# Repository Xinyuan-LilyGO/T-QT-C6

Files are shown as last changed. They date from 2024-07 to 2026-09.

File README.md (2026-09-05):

<h1 align="center">T-QT-C6</h1>

## **English** | [中文](./README_CN.md)





<p align="center">
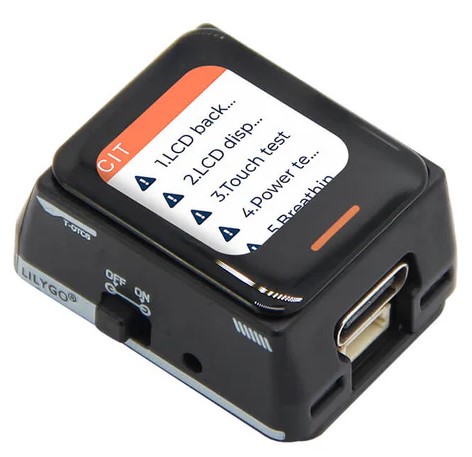
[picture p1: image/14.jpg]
T-QT-C6
  
</p>

## Overview

T-QT-C6 is a compact development board based on the ESP32-C6, with a 0.85-inch 128 × 128 LCD, capacitive touch, battery measurement, charging management, and an RGB breathing LED. An optional battery backboard adds a battery connector and an LSM6DSL inertial sensor.

[Purchase from the LILYGO store](https://lilygo.cc/products/t-qt-c6)

## Directory

- [Device Versions](#device-versions)
- [Notes](#notes)
- [Preview](#preview)
- [Supported Development Environments](#supported-development-environments)
- [Quick Start](#quick-start)
- [Examples](#examples)
- [Prebuilt Firmware](#prebuilt-firmware)
- [Hardware Modules](#hardware-modules)
- [Pin Overview](#pin-overview)
- [Power Consumption](#power-consumption)
- [Project Materials](#project-materials)
- [FAQ](#faq)

## Device Versions

| Version | Release date | Main change |
| :-- | :-- | :-- |
| T-QT-C6 V1.0 | 2023-12-20 | Initial release |
| T-QT-C6 V1.1 | 2024-03-27 | Added battery backboard support |
| T-QT-C6 V1.2 | 2024-06-13 | Replaced the charging IC with SGM41562 |
| T-QT-C6 Battery V1.2 | 2025-08-11 | Changed the battery connector to a 2-pin, 1.25 mm connector |

## Notes

- Select the connected battery backboard version in [`libraries/common/pin_config.h`](./libraries/common/pin_config.h). The default configuration is `T_QT_C6_Battery_V1_2`.
- Battery V1.2 uses a two-wire battery connection (VBAT and GND) without an external NTC thermistor. The SGM41562 application example therefore disables external NTC detection.
- `Arduino_GFX` and `cpp_bus_driver` are Git submodules. Clone this repository recursively or initialize the submodules before building.
- The factory-test example must match the charging IC fitted to the MCU board: use `Lvgl_CIT_ETA4662` for MCU V1.0/V1.1 and `Lvgl_CIT_SGM41562` for MCU V1.2.

## Preview

<p align="center">
  T-QT-C6 front view
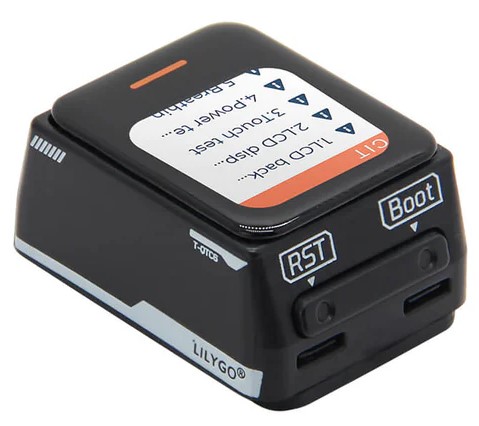
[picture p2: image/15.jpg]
T-QT-C6 side view
  
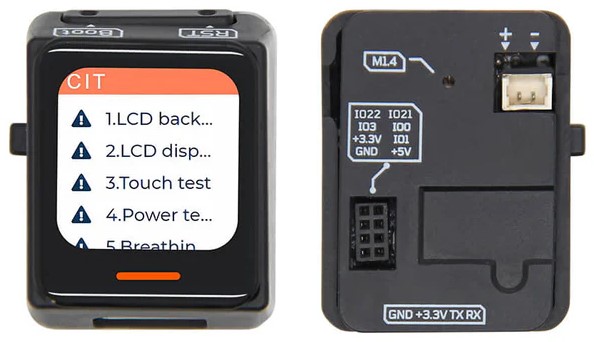
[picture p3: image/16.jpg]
T-QT-C6 rear view
  
</p>

## Supported Development Environments

| Development environment | Status | Configuration source |
| :-- | :--: | :-- |
| Arduino IDE | Supported | Use the Arduino-ESP32 version noted in [`platformio.ini`](./platformio.ini) |
| PlatformIO | Recommended | Use the repository's [`platformio.ini`](./platformio.ini) |

Framework versions, the board target, flash layout, USB CDC, and build environments are maintained in [`platformio.ini`](./platformio.ini) as the single source of truth.

## Quick Start

### Get the Source Code

Clone the project and its submodules:

```bash
git clone --recursive https://github.com/Xinyuan-LilyGO/T-QT-C6.git
cd T-QT-C6
```

If the project has already been cloned, initialize the submodules with:

```bash
git submodule update --init --recursive
```

### PlatformIO

1. Install [Visual Studio Code](https://code.visualstudio.com/) and the [PlatformIO IDE extension](https://platformio.org/install/ide?install=vscode).

2. Open [`platformio.ini`](./platformio.ini) and set `default_envs` to the required example, for example:

   ```ini
   [platformio]
   default_envs = GFX
   ```

3. Build, upload, and open the serial monitor:

   ```bash
   pio run
   pio run -t upload
   pio device monitor -b 115200
   ```

The selected environment name and `default_envs` must match because the example source directory is derived from `default_envs`.

### Arduino IDE

1. Copy all library folders from the repository's [`libraries/`](./libraries) directory to the `libraries` directory under your Arduino Sketchbook. The Sketchbook location is shown in **Arduino IDE > File > Preferences**. On Windows, the default destination is usually `Documents\Arduino\libraries`.

2. Open the `.ino` file in the required example directory.

3. Use the following Arduino IDE board settings:

| Setting | Value |
| :-- | :-- |
| Board | ESP32C6 Dev Module |
| Upload Speed | 921600 |
| CPU Frequency | 160MHz |
| Flash Mode | QIO |
| Flash Size | 4MB (32Mb) |
| Core Debug Level | None |
| Partition Scheme | Huge APP (3MB No OTA/1MB SPIFFS) |

### Examples

| Example link | Description |
| :-- | :-- |
| [`examples/`](./examples) | Current T-QT-C6 example sources |

Open the example directory for the current source and supported example list. For factory testing, select the environment that matches the board's charging IC as described in [Notes](#notes).

### Prebuilt Firmware

The following prebuilt firmware images are available.

For instructions on flashing prebuilt firmware, refer to Espressif's official [ESP firmware web flashing guide](https://docs.espressif.com/projects/esp-techpedia/en/latest/esp-friends/get-started/try-firmware/try-firmware-platform.html).

| Firmware | Flash address | Description |
| --- | --- | --- |
| [`firmware/`](./firmware) | `0x0 (merged)` | T-QT-C6 factory-test and sleep-example firmware |

> [!IMPORTANT]
> Select `ESP32-C6` when flashing T-QT-C6 firmware. Choose an image whose filename matches both the MCU board version and battery backboard version. Firmware for different hardware versions must not be mixed.

PlatformIO build artifacts are written to `.pio/build/<environment>/`. `firmware.bin` is the application image, while `firmware.factory.bin` is the merged image containing the bootloader, partition table, boot application, and firmware. The `.pio` directory is temporary and may be recreated by clean or build operations; copy any build that must be retained to another directory.

## Hardware Modules

| Module | Part | Interface / specification |
| :-- | :-- | :-- |
| MCU module | ESP32-C6-MINI-1U | RISC-V, 160 MHz, Wi-Fi 6, Bluetooth LE, IEEE 802.15.4 |
| Flash | Integrated | 4 MB |
| PSRAM | — | Not fitted |
| LCD | GC9107 (earlier) or ST7735 (latest) | 0.85-inch, 128 × 128, SPI |
| Touch | CST816T | Capacitive touch, I2C |
| Charger, MCU V1.0/V1.1 | ETA4662 | I2C |
| Charger, MCU V1.2 | SGM41562 | I2C |
| IMU, battery backboard | LSM6DSL | 6-axis accelerometer and gyroscope, I2C |
| RGB breathing LED | — | One-wire control |

## Pin Overview

Board pin definitions and hardware mappings are provided in the configuration file:

- [`pin_config.h`](./libraries/common/pin_config.h)

## Power Consumption

Measured with T-QT-C6 V1.2. See the [power-consumption test reports](./relevant_test) for the test conditions.

| Mode | Typical measured current |
| :-- | :--: |
| Light sleep | 553 µA |
| Deep sleep | 170 µA |

## Project Materials

- [Schematics](./project)
- [Datasheets](./information)
- [Test reports](./relevant_test)
- [Prebuilt firmware](./firmware)

## FAQ

<details>
<summary>Compilation reports that an Arduino_GFX or cpp_bus_driver header is missing</summary>

Initialize the Git submodules and build again:

```bash
git submodule update --init --recursive
```

</details>

<details>
<summary>The wrong example is built</summary>

Set `default_envs` in [`platformio.ini`](./platformio.ini) to the required example. This project derives `src_dir` from that value, so changing only the command-line environment is not sufficient.

</details>

<details>
<summary>Upload cannot start or the board is not detected</summary>

Connect the board with a data-capable USB cable. If automatic download mode fails, hold the **BOOT** button, start the upload, and release the button when writing begins.

</details>

<details>
<summary>There is no serial output</summary>

Use a baud rate of `115200` and select the ESP32-C6 USB serial/JTAG port. The supplied PlatformIO configuration enables USB CDC on boot.

</details>

<details>
<summary>Where are the generated firmware files?</summary>

They are located in `.pio/build/<environment>/`. Use `firmware.factory.bin` for a single merged factory image. Since `.pio` is a generated build directory, copy the image elsewhere if it needs to be kept.

</details>

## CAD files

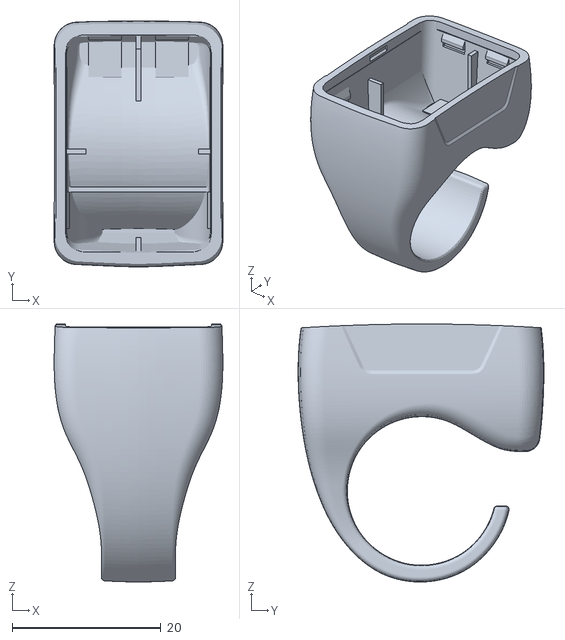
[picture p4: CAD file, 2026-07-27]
structure/FB126/fb126-huan.stl
22.7 x 33.1 x 34.7

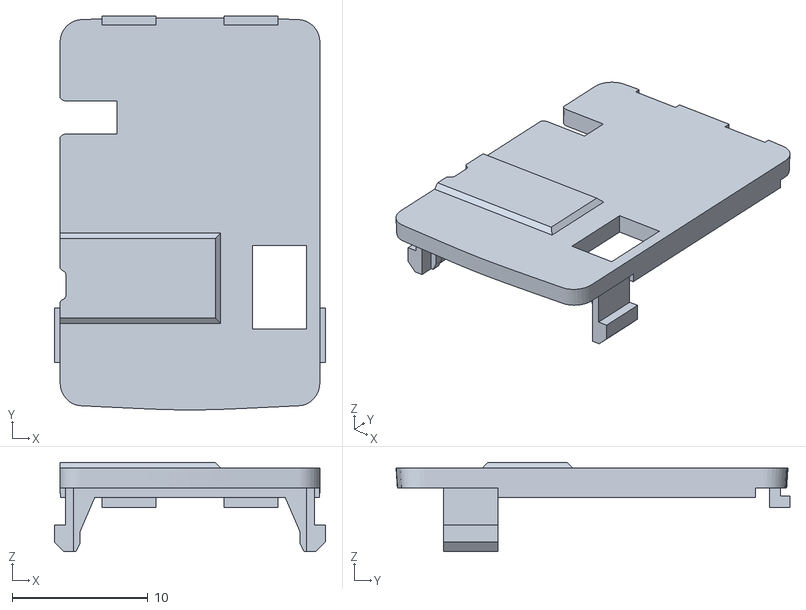
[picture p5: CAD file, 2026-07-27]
structure/FB126/fb126-gai.stl
20.0 x 29.0 x 6.57

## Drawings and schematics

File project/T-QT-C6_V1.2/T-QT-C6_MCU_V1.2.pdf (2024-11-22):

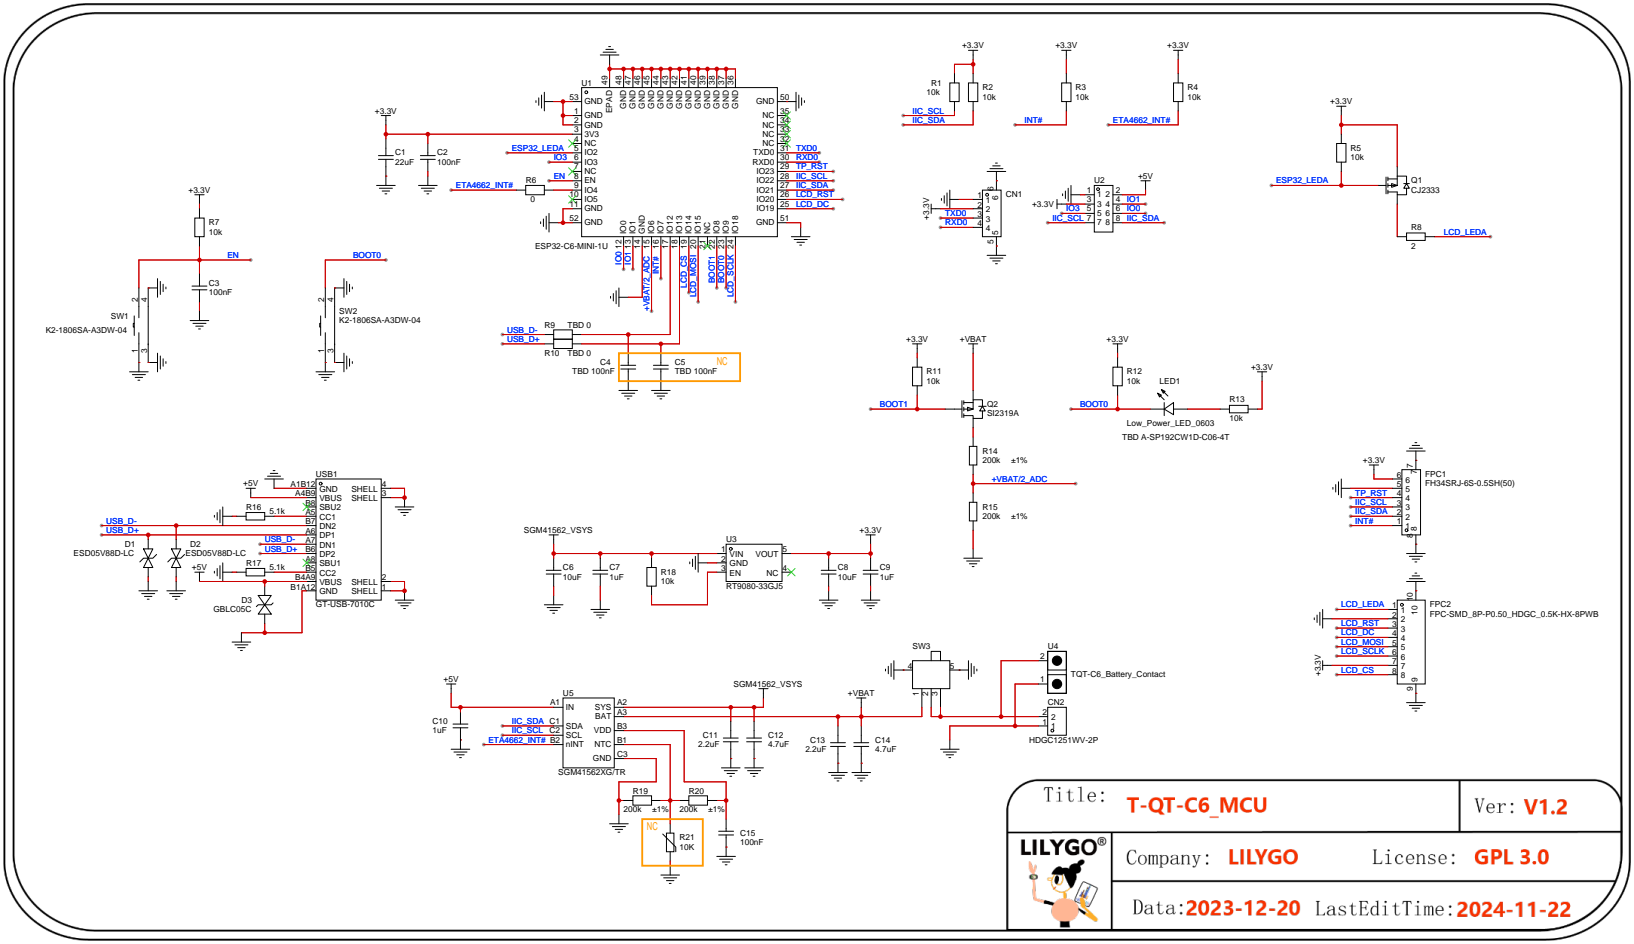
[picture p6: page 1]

GND 38 GND 39 GND 40 GND 41 GND 42 GND 43 GND 44 GND 45 GND 46 GND 47

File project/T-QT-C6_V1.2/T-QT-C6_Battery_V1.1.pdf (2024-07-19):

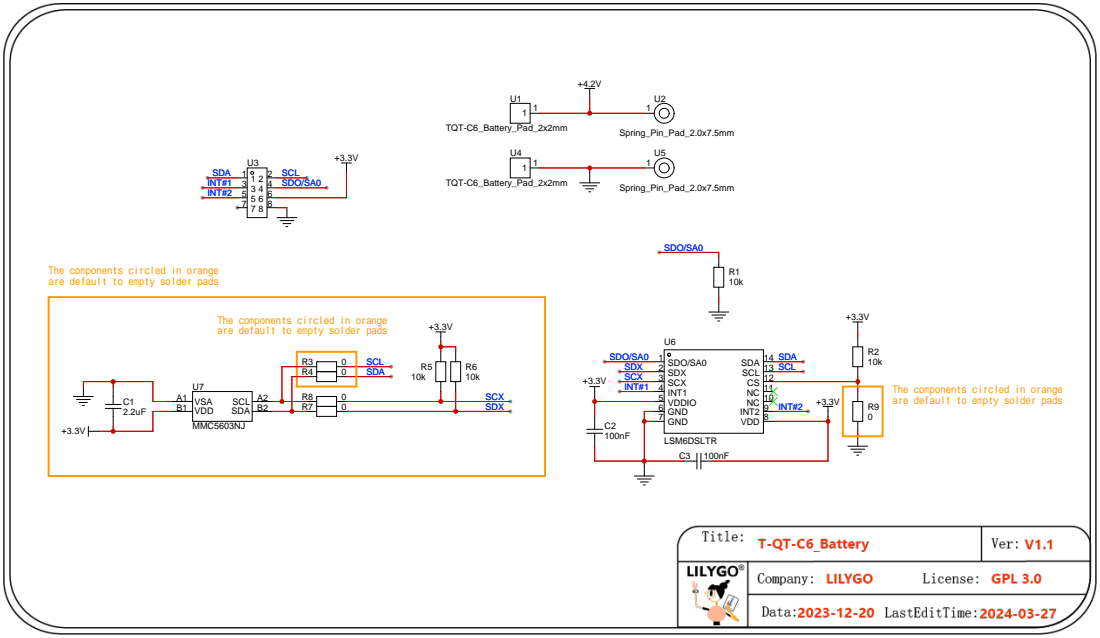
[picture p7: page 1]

The components circled in orange
are default to empty solder pads

+3.3V The components circled in orange

NC 10 NC 11 CS 12 SCL 13 SDA 14

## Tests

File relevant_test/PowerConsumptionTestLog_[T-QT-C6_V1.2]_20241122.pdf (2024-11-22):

# T-QT-C6_V1.2 Power Consumption Test Log

## 2. Modification Instructions

## 1. Test Environment Description

Test Tools | Sampling speed | Test Methodology | Input voltage | Test environment temperature
BLU939 | 100000 times/s | Battery Interface Measurement | +4.0V | 25°C/77°F

NULL

www.lilygo.cc

Date: 20241122
LastEditTime: 20241122
Test board: T-QT-C6_V1.2 (Engineering Prototype)(202405231700) Testing organization: LILYGO Laboratory

## 3. Test Physical Object Image

1.1 测试环境
1.1 Test environment
Test device | Power 3.3V | Screen | Touch | Charging chip | IMU
Corresponding
model | RT9080 | N085-1212TBWIG06-C08 | CST816T | SGM41562XG/TR | LSM6DSL

1.2 测试的器件型号
1.2 Test device model

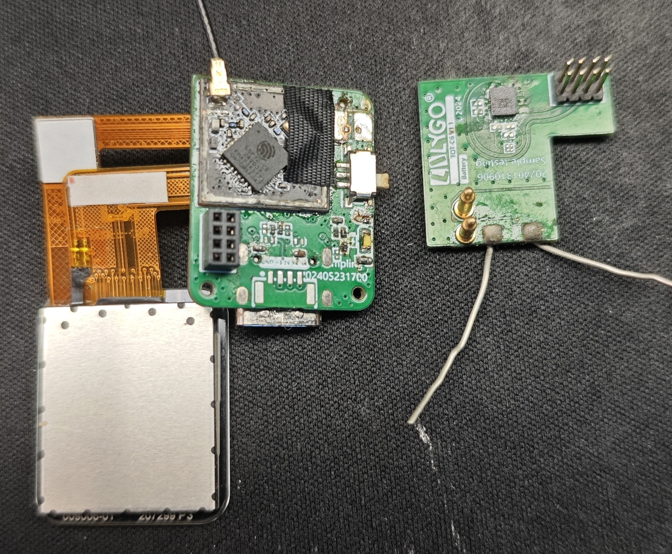
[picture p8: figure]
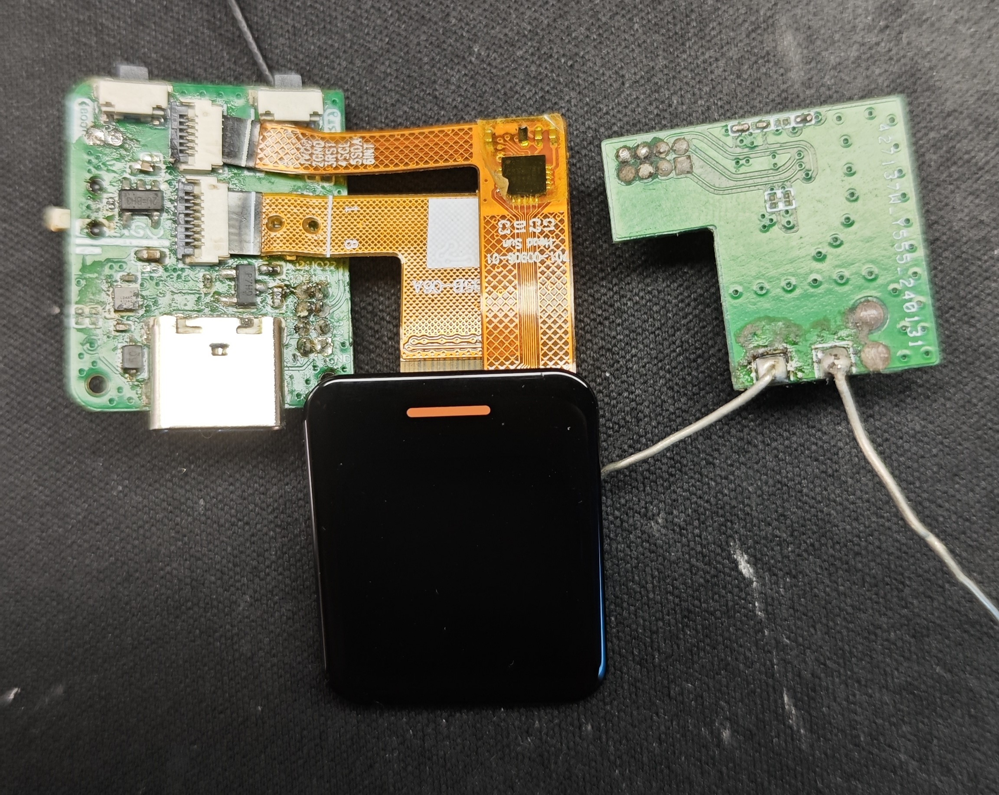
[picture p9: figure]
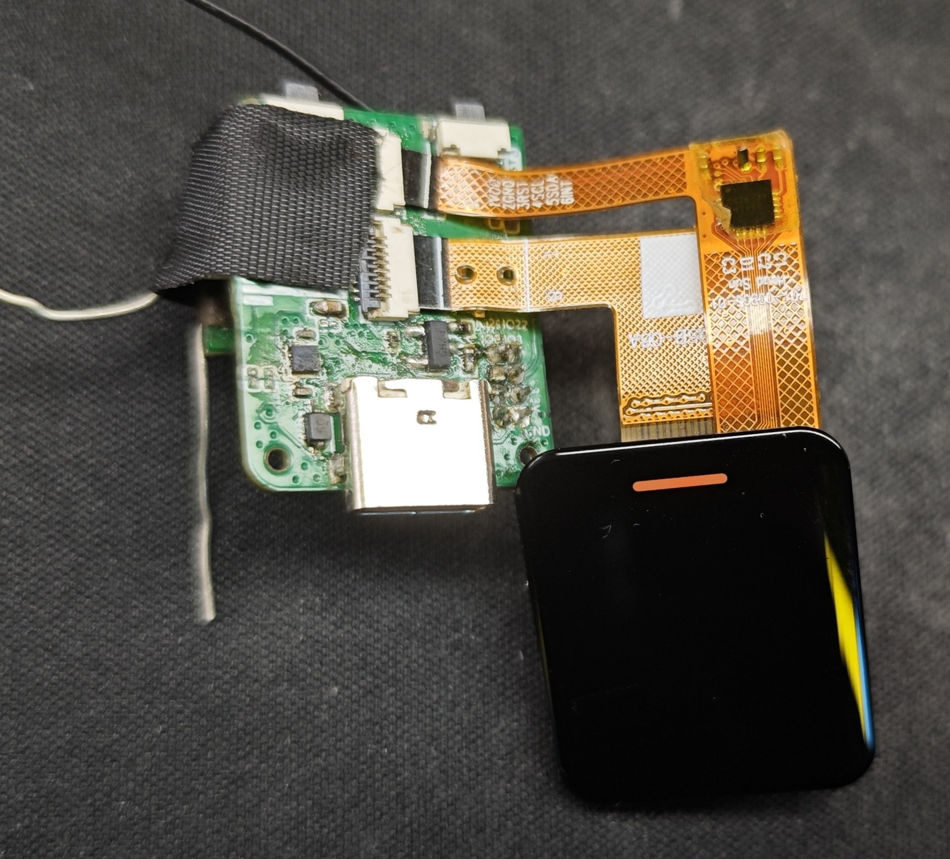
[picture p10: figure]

## 4. Program: Deep_Sleep.ino Power Consumption Test

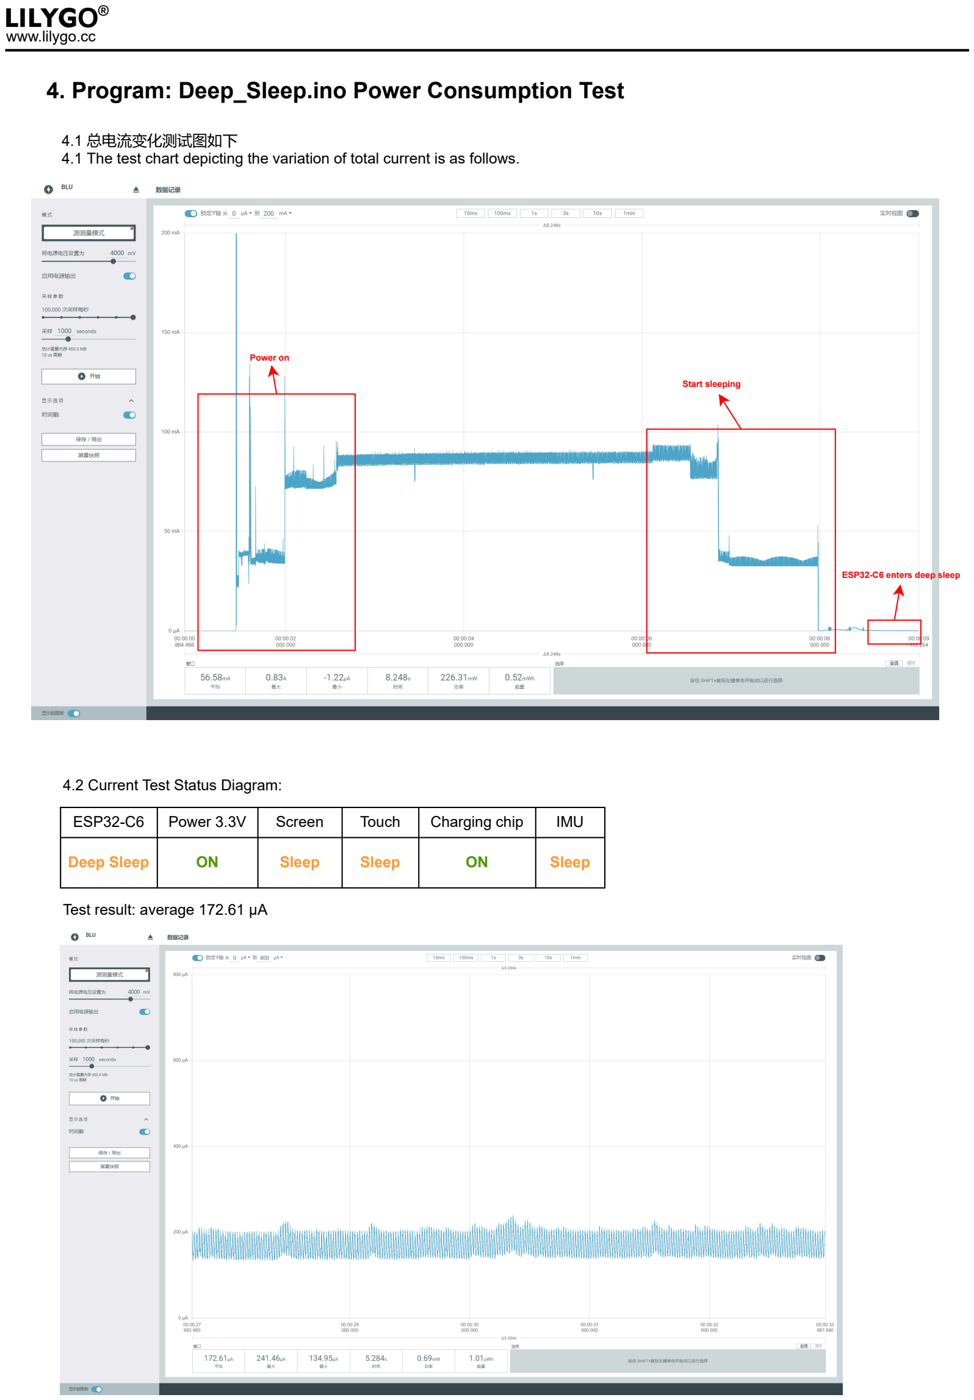
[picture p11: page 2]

4.2 Current Test Status Diagram:

Power on

4.1 总电流变化测试图如下
4.1 The test chart depicting the variation of total current is as follows.
ESP32-C6 | Power 3.3V | Screen | Touch | Charging chip | IMU
Deep Sleep | ON | Sleep | Sleep | ON | Sleep

Test result: average 172.61 μA

Start sleeping

ESP32-C6 enters deep sleep

## 5. Program: Light_Sleep.ino Power Consumption Test

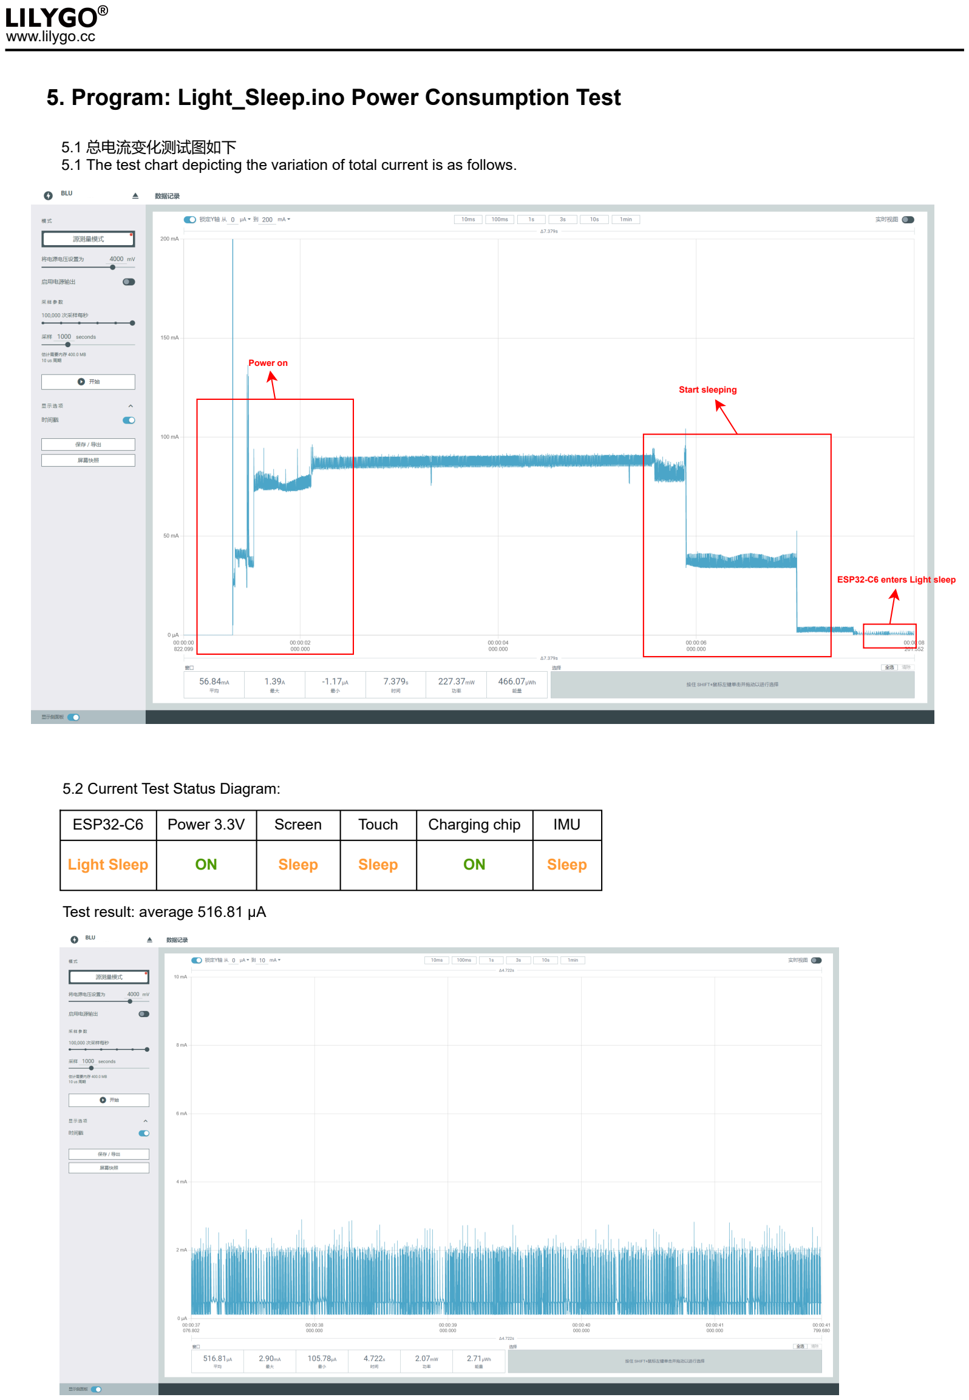
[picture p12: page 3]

5.2 Current Test Status Diagram:

Power on

5.1 总电流变化测试图如下
5.1 The test chart depicting the variation of total current is as follows.
ESP32-C6 | Power 3.3V | Screen | Touch | Charging chip | IMU
Light Sleep | ON | Sleep | Sleep | ON | Sleep

Test result: average 516.81 μA

Start sleeping

ESP32-C6 enters Light sleep

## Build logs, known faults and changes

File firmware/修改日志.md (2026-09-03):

## 202609031528
### Changed firmware
- `[TQT-C6_MCU_V1.2][TQT-C6_Battery_V1.2][Lvgl_CIT_SGM41562]_firmware_202609031528`
### Change content
- 兼容更多充电芯片SGM41562型号

## 202509180922
### Changed firmware
- `[TQT-C6_MCU_V1.2][TQT-C6_Battery_V1.2][Lvgl_CIT_SGM41562]_firmware_202509180922`
### Change content
- 修改默认进行充电,去除电压掉至2.5v停止充电操作

## 202508111745
### Changed firmware
- `[TQT-C6_MCU_V1.2][TQT-C6_Battery_V1.2][Lvgl_CIT_SGM41562]_firmware_202508111745`
### Change content
- wifi连接改成30秒

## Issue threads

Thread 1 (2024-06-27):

No platformio.ini file.

nishad2m8, 2024-06-27:
No **platformio.ini** file. Can you please check and update

Llgok, 2024-07-10:
@nishad2m8
Currently, PlatformIO does not provide support for versions of arduino-esp32-libs above V3.0. The ESP32-C6 only supports programming with the Arduino IDE and the arduino-esp32-libs library versions above V3.0. Therefore, there is currently no platformio.ini file available. If support is added in the future, it will be included accordingly.

Closed 2024-07-10.

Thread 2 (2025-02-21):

Couple of issues with T-QT-C6 with Ring.

harshaxnim, 2025-02-21:
I recently bought a T QT C6 device with the ring. It mostly works ok without the ring.

But when I attach the ring, the device becomes unresponsive to touch, and the display rendering stutters when I touch the display rather than responding to touch.

Additionally, I think the ring is not charging because the default test firmware shows `0mV` if I open `4. Power Test`.

Finally, with or without the ring, the IMU seems to be not working at all. The default test firmware says calibration successful, but neither the red circle nor the orange circle moves - see below.

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

Let me know if this there's something I can try. Thank you!

Llgok, 2025-02-22:
@harshaxnim
Hello, I suspect there might be a connection issue between the battery back panel and the main board. Please try re-plugging the back panel and try switching the example to [IMU_Level.ino](https://github.com/Xinyuan-LilyGO/T-QT-C6/blob/arduino-esp32-libs_V3.0.2/examples/IMU_Level/IMU_Level.ino) for further testing. If the problem persists, please contact customer service to replace the back panel.

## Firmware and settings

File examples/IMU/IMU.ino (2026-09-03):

/*
 *  @Description:
            LSM6DSL chip routine based on Arduino_DriveBus library
        Here are a few points to note when using this chip:
        1.When collecting data in high-performance mode, LSM6DSL may experience significant data fluctuations.
        2.When directly reading data from LSM6DSL, it is recommended to introduce a delay in the read rate in
    low-performance mode to avoid data reading failures.
        3.Calibration is required when using LSM6DSL. During calibration, ensure the device is placed upright
    and stationary. The calibration sequence should start from the gyroscope sensor to the accelerometer sensor.
 * @Author: LILYGO_L
 * @Date: 2024-02-20 17:13:03
 * @LastEditTime: 2025-06-03 11:42:27
 * @License: GPL 3.0
 */
#include "Arduino_DriveBus_Library.h"
#include "cpp_bus_driver_library.h"
#include <math.h>
#include "pin_config.h"

static size_t CycleTime1 = 0;
static size_t CycleTime2 = 0;

std::shared_ptr<Arduino_IIC_DriveBus> IIC_Bus =
    std::make_shared<Arduino_HWIIC>(IIC_SDA, IIC_SCL, &Wire);

std::unique_ptr<Arduino_IIC> LSM6DSL(new Arduino_LSM6DSL(IIC_Bus, LSM6DSL_DEVICE_ADDRESS,
                                                         DRIVEBUS_DEFAULT_VALUE, DRIVEBUS_DEFAULT_VALUE));

std::unique_ptr<Arduino_IIC> ETA4662(new Arduino_ETA4662(IIC_Bus, ETA4662_DEVICE_ADDRESS,
                                                         DRIVEBUS_DEFAULT_VALUE, DRIVEBUS_DEFAULT_VALUE));

std::shared_ptr<cpp_bus_driver::HardwareI2c1> CPP_IIC_Master_Bus =
    std::make_shared<cpp_bus_driver::HardwareI2c1>(IIC_SDA, IIC_SCL);
std::shared_ptr<cpp_bus_driver::HardwareI2c1> SGM41562_IIC_Bus =
    std::make_shared<cpp_bus_driver::HardwareI2c1>(CPP_IIC_Master_Bus);
std::unique_ptr<cpp_bus_driver::Sgm41562xx> SGM41562(
    new cpp_bus_driver::Sgm41562xx(SGM41562_IIC_Bus));

void setup()
{
    Serial.begin(115200);
    Serial.println("Ciallo");

#if defined T_QT_C6_Battery_V1_0_V1_1
    pinMode(LSM6DSL_IIC_ADDRESS_MODE, OUTPUT);
    digitalWrite(LSM6DSL_IIC_ADDRESS_MODE, LOW); // 设置LSM6DSL的IIC地址为0x6A
#elif defined T_QT_C6_Battery_V1_2
    pinMode(LSM6DSL_EN, OUTPUT);
    digitalWrite(LSM6DSL_EN, HIGH); // 开启LSM6DSL
#endif

    i2c_master_bus_handle_t sgm41562_bus_handle = nullptr;
    if (ETA4662->begin() == true)
    {
        Serial.println("ETA4662 initialization successfully");
    }
    else if (i2c_master_get_bus_handle(
                 I2C_NUM_0, &sgm41562_bus_handle) == ESP_OK &&
             CPP_IIC_Master_Bus->set_bus_handle(sgm41562_bus_handle) &&
             SGM41562->Init())
    {
        Serial.println("SGM41562 initialization successfully");
    }
    else
    {
        Serial.println("Power chip initialization failed");
    }

    while (LSM6DSL->begin() == false)
    {
        Serial.println("LSM6DSL initialization fail");
        delay(2000);
    }
    Serial.println("LSM6DSL initialization successfully");

    // 设置加速度传感器性能模式为高性能模式
    LSM6DSL->IIC_Write_Device_State(LSM6DSL->Arduino_IIC_IMU::Device::IMU_ACCELERATION_POWER_MODE,
                                    LSM6DSL->Arduino_IIC_IMU::Device_Mode::IMU_DEVICE_HIGH_POWER);
    // 设置加速度传感器灵敏度为 ±16g
    LSM6DSL->IIC_Write_Device_Value(LSM6DSL->Arduino_IIC_IMU::Device_Value::IMU_ACCELERATION_SENSITIVITY,
                                    16);

    // 设置陀螺仪传感器性能模式为高性能模式
    LSM6DSL->IIC_Write_Device_State(LSM6DSL->Arduino_IIC_IMU::Device::IMU_GYROSCOPE_POWER_MODE,
                                    LSM6DSL->Arduino_IIC_IMU::Device_Mode::IMU_DEVICE_HIGH_POWER);
    // 设置陀螺仪传感器灵敏度为 ±2000dps
    LSM6DSL->IIC_Write_Device_Value(LSM6DSL->Arduino_IIC_IMU::Device_Value::IMU_GYROSCOPE_SENSITIVITY,
                                    2000);

    // Serial.printf("\nStart calibrating the gyroscope and accelerometer\n");
    // delay(1000);
    // // 将器件静止后再校正陀螺仪传感器
    // while (LSM6DSL->IIC_Write_Device_Value(LSM6DSL->Arduino_IIC_IMU::Device_Value::IMU_GYROSCOPE_CORRECTION,
    //                                        100) == false)
    // {
    //     Serial.printf("\nLSM6DSL gyroscope correction fail\n");
    //     Serial.printf("Please ensure that the device is in a stationary state!\n\n");
    //     delay(1000);
    // }
    // Serial.printf("LSM6DSL gyroscope correction successfully\n");
    // // 将器件正放静止后再校正加速度传感器
    // // 最好在陀螺仪校正后立即进行加速度校正
    // while (LSM6DSL->IIC_Write_Device_Value(LSM6DSL->Arduino_IIC_IMU::Device_Value::IMU_ACCELERATION_CORRECTION,
    //                                        100) == false)
    // {
    //     Serial.printf("\nLSM6DSL acceleration correction fail\n");
    //     Serial.printf("Please ensure that the device is in a stationary state!\n\n");
    //     delay(1000);
    // }
    // Serial.printf("LSM6DSL acceleration correction successfully\n\n");
    // delay(1000);

    // FIFO ON
    // //  设置设备FIFO性能模式为高性能模式
    // LSM6DSL->IIC_Write_Device_State(LSM6DSL->Arduino_IIC_IMU::Device::IMU_FIFO_POWER_MODE,
    //                                 LSM6DSL->Arduino_IIC_IMU::Device_Mode::IMU_DEVICE_HIGH_POWER);
    // // 设置设备FIFO工作模式为Bypass模式
    // LSM6DSL->IIC_Write_Device_State(LSM6DSL->Arduino_IIC_IMU::Device::IMU_FIFO_WORK_MODE,
    //                                 LSM6DSL->Arduino_IIC_IMU::Device_Mode::IMU_FIFO_BYPASS);
    // // 设置设备FIFO获取数据类型为加速度和陀螺仪传感器的数据
    // LSM6DSL->IIC_Write_Device_State(LSM6DSL->Arduino_IIC_IMU::Device::IMU_FIFO_DATA_TYPE,
    //                                 LSM6DSL->Arduino_IIC_IMU::Device_Mode::IMU_FIFO_DATA_ACCELERATION_GYROSCOPE);
    // // 设置加速度传感器的FIFO的抽取因子为1
    // LSM6DSL->IIC_Write_Device_Value(LSM6DSL->Arduino_IIC_IMU::Device_Value::IMU_FIFO_ACCELERATION_FACTOR,
    //                                 1);
    // // 设置陀螺仪传感器的FIFO的抽取因子为1
    // LSM6DSL->IIC_Write_Device_Value(LSM6DSL->Arduino_IIC_IMU::Device_Value::IMU_FIFO_GYROSCOPE_FACTOR,
    //                                 1);
}
void loop()
{
    // if (millis() > CycleTime1)
    // {
    //     Serial.printf("--------------------LSM6DSL--------------------\n");
    //     Serial.printf("System running time: %d\n\n", (uint32_t)millis() / 1000);
    //     Serial.printf("IIC_Bus.use_count(): %d\n\n", (int32_t)IIC_Bus.use_count());

    //     Serial.printf("ID: %#X \n", (int32_t)LSM6DSL->IIC_Device_ID());

    //     // 只有在启动加速度或陀螺仪的时候才能查看设备温度
    //     Serial.printf("IMU Device Temperature: %.3f ^C \n",
    //                   LSM6DSL->IIC_Read_Device_Value(LSM6DSL->Arduino_IIC_IMU::Value_Information::IMU_TEMPERATURE_VALUE));

    //     Serial.printf("--------------------LSM6DSL--------------------\n");
    //     CycleTime1 = millis() + 5000;
    // }

    if (millis() > CycleTime2)
    {
        // FIFO OFF
        // Arduino-IDE Serial Plotter
        // IMU Acceleration
        // 单位mg
        // Serial.printf("%.6f,%.6f", (float)-1200, (float)1200);
        // Serial.printf(",%.6f",
        //               LSM6DSL->IIC_Read_Device_Value(LSM6DSL->Arduino_IIC_IMU::Value_Information::IMU_ACCELERATION_X_SIGNED));
        // delay(5);
        // Serial.printf(",%.6f",
        //               LSM6DSL->IIC_Read_Device_Value(LSM6DSL->Arduino_IIC_IMU::Value_Information::IMU_ACCELERATION_Y_SIGNED));
        // delay(5);
        // Serial.printf(",%.6f",
        //               LSM6DSL->IIC_Read_Device_Value(LSM6DSL->Arduino_IIC_IMU::Value_Information::IMU_ACCELERATION_Z_SIGNED));
        // delay(5);
        // Serial.printf("\n");

        // g单位转化为m/s²单位
        // 将加速度计（g）的值乘以9.81即可将其转换为米每秒的平方
        // Serial.printf("%.6f,%.6f", (float)-12, (float)12);
        // Serial.printf(",%.6f",
        //               LSM6DSL->IIC_Read_Device_Value(LSM6DSL->Arduino_IIC_IMU::Value_Information::IMU_ACCELERATION_X_SIGNED) / 1000 * 9.81);
        // delay(5);
        // Serial.printf(",%.6f",
        //               LSM6DSL->IIC_Read_Device_Value(LSM6DSL->Arduino_IIC_IMU::Value_Information::IMU_ACCELERATION_Y_SIGNED) / 1000 * 9.81);
        // delay(5);
        // Serial.printf(",%.6f",
        //               LSM6DSL->IIC_Read_Device_Value(LSM6DSL->Arduino_IIC_IMU::Value_Information::IMU_ACCELERATION_Z_SIGNED) / 1000 * 9.81);
        // delay(5);
        // Serial.printf("\n");

        // IMU Gyroscope
        // 单位dps/s
        // Serial.printf("%.6f,%.6f", (float)-2000, (float)2000);
        // Serial.printf(",%.6f",
        //               LSM6DSL->IIC_Read_Device_Value(LSM6DSL->Arduino_IIC_IMU::Value_Information::IMU_GYROSCOPE_X_SIGNED) / 1000);
        // delay(5);
        // Serial.printf(",%.6f",
        //               LSM6DSL->IIC_Read_Device_Value(LSM6DSL->Arduino_IIC_IMU::Value_Information::IMU_GYROSCOPE_Y_SIGNED) / 1000);
        // delay(5);
        // Serial.printf(",%.6f",
        //               LSM6DSL->IIC_Read_Device_Value(LSM6DSL->Arduino_IIC_IMU::Value_Information::IMU_GYROSCOPE_Z_SIGNED) / 1000);
        // delay(5);
        // Serial.printf("\n");

        // dps/s单位转化为rad/s单位
        // 一圈等于360度或2π弧度 每秒转的度数需要乘以 π/180 来转换为弧度每秒
        Serial.printf("%.6f,%.6f", (float)-10, (float)10);
        Serial.printf(",%.6f",
                      (acos(-1) / 180) * LSM6DSL->IIC_Read_Device_Value(LSM6DSL->Arduino_IIC_IMU::Value_Information::IMU_GYROSCOPE_X_SIGNED) / 1000);
        delay(10);
        Serial.printf(",%.6f",
                      (acos(-1) / 180) * LSM6DSL->IIC_Read_Device_Value(LSM6DSL->Arduino_IIC_IMU::Value_Information::IMU_GYROSCOPE_Y_SIGNED) / 1000);
        delay(10);
        Serial.printf(",%.6f\n",
                      (acos(-1) / 180) * LSM6DSL->IIC_Read_Device_Value(LSM6DSL->Arduino_IIC_IMU::Value_Information::IMU_GYROSCOPE_Z_SIGNED) / 1000);
        delay(10);

        // FIFO ON
        // // 重启FIFO清除FIFO缓存中的数据
        // LSM6DSL->IIC_Write_Device_State(LSM6DSL->Arduino_IIC_IMU::Device::IMU_FIFO_WORK_MODE,
        //                                 LSM6DSL->Arduino_IIC_IMU::Device_Mode::IMU_FIFO_BYPASS);
        // LSM6DSL->IIC_Write_Device_State(LSM6DSL->Arduino_IIC_IMU::Device::IMU_FIFO_WORK_MODE,
        //                                 LSM6DSL->Arduino_IIC_IMU::Device_Mode::IMU_FIFO_NORMAL);

        // // DATA_PATTERN 范围为0-1023
        // Serial.printf("%d ",
        //               (int16_t)LSM6DSL->IIC_Read_Device_Value(LSM6DSL->Arduino_IIC_IMU::Value_Information::IMU_FIFO_DATA_PATTERN));
        // for (int i = 0; i < 1024; i++)
        // {
        //     Serial.printf("%d ",
        //                   (int16_t)LSM6DSL->IIC_Read_Device_Value(LSM6DSL->Arduino_IIC_IMU::Value_Information::IMU_FIFO_DATA));
        // }
        // Serial.printf("\n");

        CycleTime2 = millis() + 50;
    }
}

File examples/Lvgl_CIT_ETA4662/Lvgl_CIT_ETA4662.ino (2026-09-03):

/*
 * @Description: This is a user testing program CIT written for TQT-C6.
 * @Author: LILYGO_L
 * @Date: 2023-09-22 11:59:37
 * @LastEditTime: 2025-09-18 09:17:47
 * @License: GPL 3.0
 */
#include "custom.h"
#include "lvgl.h"
#include "gui_guider.h"
#include "events_init.h"

uint64_t Window_CycleTime1 = 0;

static lv_disp_draw_buf_t draw_buf;
static lv_color_t *disp_draw_buf;
lv_disp_drv_t disp_drv;

Arduino_DataBus *bus = new Arduino_HWSPI(
    LCD_DC /* DC */, LCD_CS /* CS */, LCD_SCLK /* SCK */, LCD_MOSI /* MOSI */, -1 /* MISO */); // Software SPI

Arduino_GFX *gfx = new T_QT_C6_LCD_CLASS(
    bus, LCD_RST /* RST */, 0 /* rotation */, T_QT_C6_LCD_IPS /* IPS */,
    LCD_WIDTH /* width */, LCD_HEIGHT /* height */,
    T_QT_C6_LCD_COL_OFFSET_1 /* col offset 1 */, T_QT_C6_LCD_ROW_OFFSET_1 /* row offset 1 */,
    T_QT_C6_LCD_COL_OFFSET_2 /* col offset 2 */, T_QT_C6_LCD_ROW_OFFSET_2 /* row offset 2 */);

std::shared_ptr<Arduino_IIC_DriveBus> IIC_Bus =
    std::make_shared<Arduino_HWIIC>(IIC_SDA, IIC_SCL, &Wire);

void Arduino_IIC_Touch_Interrupt(void);

std::unique_ptr<Arduino_IIC> CST816T(new Arduino_CST816x(IIC_Bus, CST816T_DEVICE_ADDRESS,
                                                         TP_RST, TP_INT, Arduino_IIC_Touch_Interrupt));
std::unique_ptr<Arduino_IIC> ETA4662(new Arduino_ETA4662(IIC_Bus, ETA4662_DEVICE_ADDRESS,
                                                         DRIVEBUS_DEFAULT_VALUE, DRIVEBUS_DEFAULT_VALUE));
std::unique_ptr<Arduino_IIC> LSM6DSL(new Arduino_LSM6DSL(IIC_Bus, LSM6DSL_DEVICE_ADDRESS,
                                                         DRIVEBUS_DEFAULT_VALUE, DRIVEBUS_DEFAULT_VALUE));

void Arduino_IIC_Touch_Interrupt(void)
{
    CST816T->IIC_Interrupt_Flag = true;
}

lv_ui guider_ui;
Lvgl_CIT_UI CIT_UI;

/* Display flushing */
void my_disp_flush(lv_disp_drv_t *disp, const lv_area_t *area, lv_color_t *color_p)
{
    uint32_t w = (area->x2 - area->x1 + 1);
    uint32_t h = (area->y2 - area->y1 + 1);

#if (LV_COLOR_16_SWAP != 0)
    gfx->draw16bitBeRGBBitmap(area->x1, area->y1, (uint16_t *)&color_p->full, w, h);
#else
    gfx->draw16bitRGBBitmap(area->x1, area->y1, (uint16_t *)&color_p->full, w, h);
#endif

    lv_disp_flush_ready(disp);
}

/*Read the touchpad*/
void my_touchpad_read(lv_indev_drv_t *indev_drv, lv_indev_data_t *data)
{
    if (CST816T->IIC_Interrupt_Flag == true)
    {
        CST816T->IIC_Interrupt_Flag = false;

        if ((uint32_t)CST816T->IIC_Read_Device_Value(CST816T->Arduino_IIC_Touch::Value_Information::TOUCH_COORDINATE_X) == 60 &&
            (uint32_t)CST816T->IIC_Read_Device_Value(CST816T->Arduino_IIC_Touch::Value_Information::TOUCH_COORDINATE_Y) == 150)
        {
        }
        else
        {
            data->state = LV_INDEV_STATE_PR;

            /*Set the coordinates*/
            data->point.x = (uint32_t)CST816T->IIC_Read_Device_Value(CST816T->Arduino_IIC_Touch::Value_Information::TOUCH_COORDINATE_X);
            data->point.y = (uint32_t)CST816T->IIC_Read_Device_Value(CST816T->Arduino_IIC_Touch::Value_Information::TOUCH_COORDINATE_Y);

            // Serial.printf("Fingers Number:%d\n",
            //             (uint32_t)CST816T->IIC_Read_Device_Value(CST816T->Arduino_IIC_Touch::Value_Information::TOUCH_FINGER_NUMBER));
            // Serial.printf("Touch X:%d Y:%d\n",
            //             (uint32_t)CST816T->IIC_Read_Device_Value(CST816T->Arduino_IIC_Touch::Value_Information::TOUCH_COORDINATE_X),
            //             (uint32_t)CST816T->IIC_Read_Device_Value(CST816T->Arduino_IIC_Touch::Value_Information::TOUCH_COORDINATE_Y));
        }
    }
    else
    {
        data->state = LV_INDEV_STATE_REL;
    }
}

void lvgl_initialization(void)
{
    lv_init();

    CIT_UI.LCD_Width = gfx->width();
    CIT_UI.LCD_Height = gfx->height();

    disp_draw_buf = (lv_color_t *)heap_caps_malloc(sizeof(lv_color_t) * CIT_UI.LCD_Width * 40, MALLOC_CAP_INTERNAL | MALLOC_CAP_8BIT);

    while (!disp_draw_buf)
    {
        Serial.println("LVGL disp_draw_buf allocate failed!");
        delay(1000);
    }

    lv_disp_draw_buf_init(&draw_buf, disp_draw_buf, NULL, CIT_UI.LCD_Width * 40);

    /* Initialize the display */
    lv_disp_drv_init(&disp_drv);
    /* Change the following line to your display resolution */
    disp_drv.hor_res = CIT_UI.LCD_Width;
    disp_drv.ver_res = CIT_UI.LCD_Height;
    disp_drv.flush_cb = my_disp_flush;
    disp_drv.draw_buf = &draw_buf;
    lv_disp_drv_register(&disp_drv);

    /*Initialize the (dummy) input device driver*/
    static lv_indev_drv_t indev_drv;
    lv_indev_drv_init(&indev_drv);
    indev_drv.type = LV_INDEV_TYPE_POINTER;
    indev_drv.read_cb = my_touchpad_read;
    lv_indev_drv_register(&indev_drv);
}

void setup()
{
    Serial.begin(115200);
    Serial.println("Ciallo");
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

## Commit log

2024-01-06 Fix WIFI connection system restart stripe
    [ETA4662.ino]
2024-09-25 Correct the deep sleep power consumption test information.
2024-11-22 Optimize power consumption
2024-11-22 Improve power consumption
2024-11-22 Update the relevant power consumption test information
2025-08-25 update Arduino_DriveBus
2025-09-18 modify the default charging to remove the operation of stopping charging when the voltage drops to 2.5v
2026-07-27 update structure
    [fb126-gai.stl, fb126-huan.stl]
2026-08-17 feat: add PlatformIO support and firmware merge tooling
    - configure Arduino-ESP32 3.0.2 environments
    - cycle GFX display through RGB, white, and black
    - add firmware merge script with automatic chip detection
2026-08-17 feat: add selectable ST7735 and GC9107 display drivers
    - add centralized LCD driver selection macros
    - configure ST7735 offsets, color order, and inversion
    - update all display examples to use the selected driver
    - keep GC9107 compatibility
2026-09-03 feat: upgrade Arduino-ESP32 to 3.3.9 and update hardware driver support
    - upgrade Arduino-ESP32 from 3.0.2 to 3.3.9 with ESP-IDF 5.5.4
    - update the PlatformIO configuration to use pioarduino 55.03.39
    - replace the bundled Arduino_GFX library with a Git submodule
    - support GC9107 and the latest ST7735 display
    - migrate SGM41562 examples to cpp_bus_driver
    - update charger information output and LVGL factory tests
    - rename Mylibrary to common
    - update prebuilt firmware and changelog
    - remove debug examples, generated build files, obsolete tools, and unused images
    - simplify the English and Chinese README files
    [Battery_Voltage.ino, Breathing_Light.ino, CST816T.ino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]
